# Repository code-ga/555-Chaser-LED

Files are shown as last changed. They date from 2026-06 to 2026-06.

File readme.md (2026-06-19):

# 555 Chaser LED

This is the one led board with 5 effects. These effects are:

- Blinky effect (each led will light-up then off for next led)
- Bit Counting (That is the calculator with led)
- Bar led ( These Stack up each clock )
- Breath effect ( fade up and fade down )
- On Mode ( their light up all led their have )

This is the result board

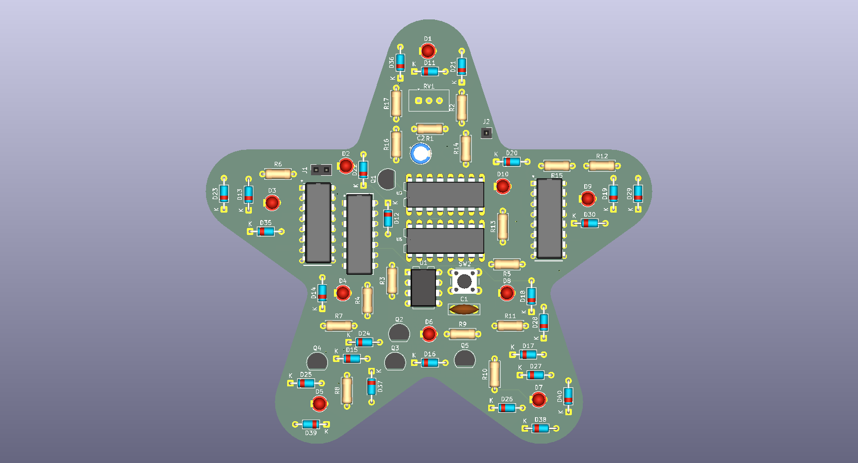
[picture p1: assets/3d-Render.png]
3D-Rendering


Also for someone want to know how that work

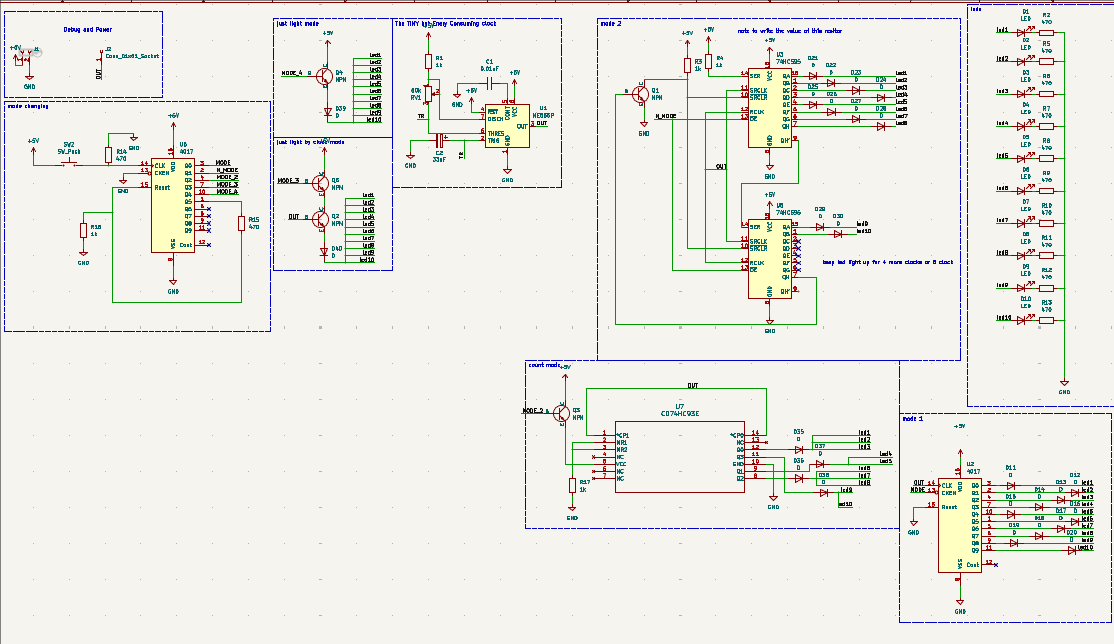
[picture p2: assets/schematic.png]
schematic


Also with the BOM (bill of material) of project is

| Reference | Qty | Value | Footprint | Datasheet | LCSC Part # | DIGIKEY_LINK | Price |
|---|-----|---|---|---|---|---|---|
| C1 | 1 | 0.01uF | Capacitor_THT:C_Disc_D7.5mm_W2.5mm_P5.00mm | | C52205045 | | 0.56  |
| C2 | 1 | 33uF | Capacitor_THT:CP_Radial_D5.0mm_P2.00mm | | C20539524 | | 0.74  |
| D1,D2,D3,D4,D5,D6,D7,D8,D9,D10 | 10  | LED | LED_THT:LED_D3.0mm | | C99772 | | 0.73  |
| D11,D12,D13,D14,D15,D16,D17,D18,D19,D20,D21,D22,D23,D24,D25,D26,D27,D28,D29,D30,D35,D36,D37,D38,D39,D40 | 26  | D | Diode_THT:D_DO-35_SOD27_P7.62mm_Horizontal | | C402212 | | 0.47  |
| J1 | 1 | | Connector_PinSocket_2.54mm:PinSocket_1x02_P2.54mm_Vertical | | C7499322 | | 0.46  |
| J2 | 1 | Conn_01x01_Socket | Connector_PinSocket_2.54mm:PinSocket_1x01_P2.54mm_Vertical | | C6302252 | | 1.15  |
| Q1,Q2,Q3,Q4,Q5 | 5 | NPN | Package_TO_SOT_THT:TO-92_Inline | https://ngspice.sourceforge.io/docs/ngspice-html-manual/manual.xhtml#cha_BJTs | C22751480 | | 0.75  |
| R1,R3,R4,R16,R17 | 5 | 1k | Resistor_THT:R_Axial_DIN0207_L6.3mm_D2.5mm_P7.62mm_Horizontal | | C3359542 | | 1.14  |
| R2,R5,R6,R7,R8,R9,R10,R11,R12,R13,R14,R15 | 12  | 470 | Resistor_THT:R_Axial_DIN0207_L6.3mm_D2.5mm_P7.62mm_Horizontal | | C1754684 | | 2.74  |
| RV1 | 1 | 50k | Potentiometer_THT:Potentiometer_Vishay_T93YA_Vertical | | C7061697 | | 3.2 |
| SW2 | 1 | SW_Push | Button_Switch_THT:SW_PUSH_6mm_H9.5mm | | C2689645 | https://www.digikey.com/en/products/detail/c-k/PVA1-OA-H1-1-2N-V2/417717 | 3.04  |
| U1 | 1 | NE555P | Package_DIP:DIP-8_W7.62mm | http://www.ti.com/lit/ds/symlink/ne555.pdf | C46749 | | 1.36  |
| U2,U6 | 2 | 4017 | CD4017BE:N16 | http://www.intersil.com/content/dam/Intersil/documents/cd40/cd4017bms-22bms.pdf | C32710674 | | 0.70  |
| U3,U5 | 2 | 74HC595 | 74HC595N:DIP16-2.54-20.32X5.84MM | http://www.ti.com/lit/ds/symlink/sn74hc595.pdf | C78711 | | 2.56  |
| U7 | 1 | CD74HC93E | 74HC93:N14 | https://www.ti.com/lit/gpn/cd74hc93 | C20345323 | | 2.29  |

[lcsc bom price](./assets/export_project_20260619_130623.xls)

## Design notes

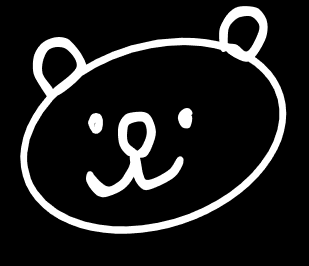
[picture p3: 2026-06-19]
assets/Merry Chrismas 1.png

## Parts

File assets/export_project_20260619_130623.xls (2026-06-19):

555-Chaser-LED.csv |  |  |  |  |  |  |  |  |  | LCSC BOM Quotation
 |  |  |  |  |  |  |  |  |  | BOM Date Created：19/06/26 01:09:42 |  |  |  | BOM Export Date: 19/06/26 13:06:23 |  |  |  | The matching result is a real-time query result, availability and prices may fluctuate. Backorder items are estimated prices for your reference, please submit "Create Quote" to get the real price. All information is provided "as is" and is subject to change without notice. Any use made of the information provided is without recourse to LCSC and at the user's risk.
 |  |  |  |  |  |  |  |  |  | EST TOTAL :$19.20 |  |  |  | Website：https://www.lcsc.com/bom | https://www.lcsc.com/bom | https://www.lcsc.com/bom | https://www.lcsc.com/bom
Uploaded data |  |  |  |  |  |  |  |  |  | LCSC Matching Results
LCSC# | Mfr. | Mrf# | Description | Package | Value | Customer Part Number | Quantity | Target Price(USD) | Target Lead Time(Business Days) | Mrf# | Mfr. | Order Qty. | Unit Price(USD) | Ext.Price(USD) | LCSC# | Package | Min | Mult | SPQ | Availability | Stock Status | Customer Notes | Description | Matched status | Product Link
C20539524 |  |  | 33uF | Capacitor_THT:CP_Radial_D5.0mm_P2.00mm |  | - | 1 |  |  | NPXB0801H330MJTM | Ymin | 5 | 0.1473 | 0.74 | C20539524 | Through Hole,D5xL8mm | 5 | 5 | 1000 | 705 | In Stock |  | 33uF ±20% 50V Through Hole,D5xL8mm 2000hrs@105℃ | Exact Matches | https://www.lcsc.com/product-detail/C20539524.html
C99772 |  |  | LED | LED_THT:LED_D3.0mm |  | - | 10 |  |  | 204-10SURD/S530-A3 | EVERLIGHT | 20 | 0.0365 | 0.73 | C99772 | Through Hole,D=3mm | 20 | 20 | 1000 | 96420 | In Stock |  | Red 632nm LED Indication - Discrete 2V Through Hole,D=3mm | Exact Matches | https://www.lcsc.com/product-detail/C99772.html
C402212 |  |  | D | Diode_THT:D_DO-35_SOD27_P7.62mm_Horizontal |  | - | 26 |  |  | 1N4148 | LGE | 50 | 0.0094 | 0.47 | C402212 | DO-35 | 50 | 50 | 5000 | 244100 | In Stock |  | Diode 75V 150mA Through Hole DO-35 | Exact Matches | https://www.lcsc.com/product-detail/C402212.html
C7499322 |  |  |  | Connector_PinSocket_2.54mm:PinSocket_1x02_P2.54mm_Vertical |  | - | 1 |  |  | ZX-PM2.54-1-2PY | Megastar | 5 | 0.0919 | 0.46 | C7499322 | Through Hole,P=2.54mm | 5 | 5 | 1000 | 31150 | In Stock |  | Female Header 2 Position 2.54mm Pitch Single Row Through Hole -40℃~+105℃ | Exact Matches | https://www.lcsc.com/product-detail/C7499322.html
C6302252 |  |  | Conn_01x01_Socket | Connector_PinSocket_2.54mm:PinSocket_1x01_P2.54mm_Vertical |  | - | 1 |  |  | SSW-101-03-G-S | Samtec | 1 | 1.1458 | 1.15 | C6302252 | Through Hole | 1 | 1 | 1000 | 34 | In Stock |  | Female Header 1 Position Single Row Through Hole -55℃~+125℃ | Exact Matches | https://www.lcsc.com/product-detail/C6302252.html
C22751480 |  |  | NPN | Package_TO_SOT_THT:TO-92_Inline |  | - | 5 |  |  | 2N4401052 | ALJ | 50 | 0.0149 | 0.75 | C22751480 | TO-92 | 50 | 50 | 1000 | 21000 | In Stock |  | Bipolar (BJT) Transistor NPN 40V 600mA 250MHz 1.5W Through Hole TO-92 | Exact Matches | https://www.lcsc.com/product-detail/C22751480.html
C3359542 |  |  | 1k | Resistor_THT:R_Axial_DIN0207_L6.3mm_D2.5mm_P7.62mm_Horizontal |  | - | 5 |  |  | MBB0207VD1001BC100 | VISHAY | 5 | 0.2284 | 1.14 | C3359542 | Through Hole,D2.5xL6.3mm | 1 | 1 | 1000 | 0 | Backordered |  | 1kΩ 400mW Metal Film Resistor ±25ppm/℃ ±0.1% Through Hole,D2.5xL6.3mm Through Hole Resistors RoHS | Exact Matches | https://www.lcsc.com/product-detail/C3359542.html
C1754684 |  |  | 470 | Resistor_THT:R_Axial_DIN0207_L6.3mm_D2.5mm_P7.62mm_Horizontal |  | - | 12 |  |  | PNP100JR-52-0R47 | YAGEO | 12 | 0.0507 | 0.61 | C1754684 | Through Hole,D2.5xL6.3mm | 1 | 1 | 5000 | 0 | Backordered |  | 470mΩ ±5% 1W Through Hole,D2.5xL6.3mm Wirewound Resistor | Exact Matches | https://www.lcsc.com/product-detail/C1754684.html
C7061697 |  |  | 50k | Potentiometer_THT:Potentiometer_Vishay_T93YA_Vertical |  | - | 1 |  |  | T93YA503KT20 | VISHAY | 1 | 3.2014 | 3.20 | C7061697 | Through Hole | 1 | 1 | 50 | 80 | In Stock |  | 50kΩ ±10% 500mW Through Hole Potentiometers, Variable Resistors | Exact Matches | https://www.lcsc.com/product-detail/C7061697.html
C2689645 |  |  | SW_Push | Button_Switch_THT:SW_PUSH_6mm_H9.5mm |  | - | 1 |  |  | PVA1OAH41.2NV2 | C&K | 1 | 3.0387 | 3.04 | C2689645 | Through Hole | 1 | 1 | 1500 | 1494 | In Stock |  | Without Non-Latching Double pole single throw Through Hole Square Plunger 1.2N Through Hole Pushbutton Switches RoHS | Exact Matches | https://www.lcsc.com/product-detail/C2689645.html
C46749 |  |  | NE555P | Package_DIP:DIP-8_W7.62mm |  | - | 1 |  |  | NE555P | TI | 5 | 0.2720 | 1.36 | C46749 | DIP-8 | 5 | 5 | 50 | 10420 | In Stock |  | DIP-8 Programmable Timers and Oscillators RoHS | Exact Matches | https://www.lcsc.com/product-detail/C46749.html
C32710674 |  |  | 4017 | CD4017BE:N16 |  | - | 2 |  |  | CD4017BE(LX) | lingxingic | 5 | 0.1399 | 0.70 | C32710674 | DIP-16 | 5 | 5 | 25 | 1640 | In Stock |  | Rising Edge 1 11MHz DIP-16 Counters, Dividers RoHS | Exact Matches | https://www.lcsc.com/product-detail/C32710674.html
C78711 |  |  | 74HC595 | 74HC595N:DIP16-2.54-20.32X5.84MM |  | - | 2 |  |  | SN74HC595N | TI | 2 | 1.2801 | 2.56 | C78711 | DIP-16 | 1 | 1 | 25 | 627 | In Stock |  | 2V~6V 1 6mA 26ns@6V,50pF Serial-to-Serial or Parallel DIP-16 Shift Registers RoHS | Exact Matches | https://www.lcsc.com/product-detail/C78711.html
C20345323 |  |  | CD74HC93E | 74HC93:N14 |  | - | 1 |  |  | CD74HC93EE4 | TI | 1 | 2.2862 | 2.29 | C20345323 | PDIP-14 | 1 | 1 | 25 | 0 | Backordered |  | PDIP-14 Counters, Dividers RoHS | Exact Matches | https://www.lcsc.com/product-detail/C20345323.html

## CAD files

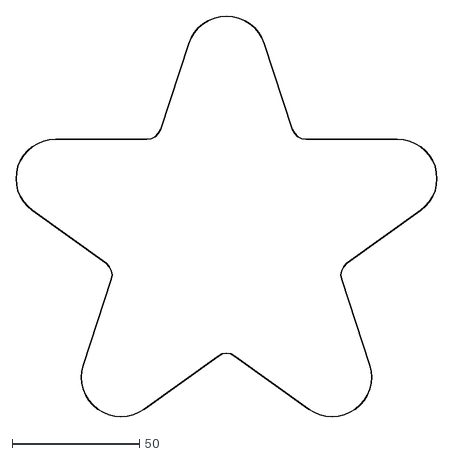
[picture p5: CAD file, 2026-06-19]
assets/vecteezy_colorful-cute-doodle-star-vector-illustration_13592912.dxf
165.6 x 157.4

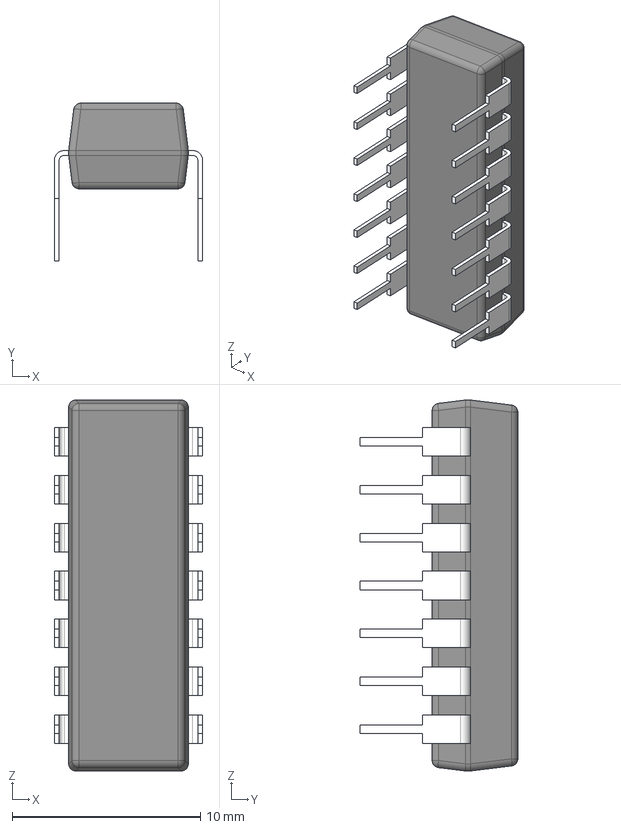
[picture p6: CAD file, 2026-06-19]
CD74HC93E/N0014A.stp
7.87 x 8.37 x 19.7 mm
BODY_N0014A_AF0
LEAD_N0014A_AF1
LEAD_N0014A x 10
LEAD_N0014A_AF3
LEAD_N0014A_AF0
LEAD_N0014A_AF2

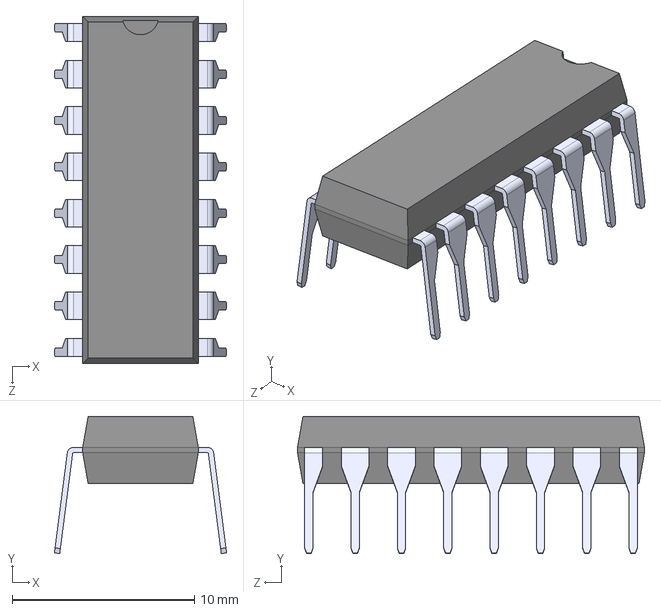
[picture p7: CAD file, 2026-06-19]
LOGIC-74HC595N_DIP16_/74HC595N.STEP
9.44 x 7.53 x 19.0 mm

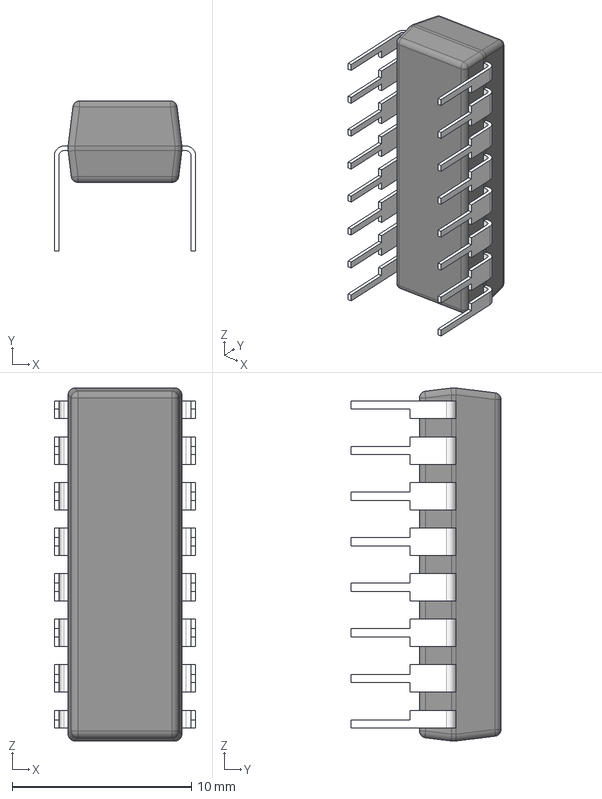
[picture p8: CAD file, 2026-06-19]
ul_CD4017BE/N0016A.stp
7.87 x 8.37 x 19.7 mm
BODY_N0016A_AF0
LEAD_N0016A_AF1
LEAD_N0016A x 10
LEAD_N0016A_AF3
LEAD_N0016A_AF5
LEAD_N0016A_AF0
LEAD_N0016A_AF2
LEAD_N0016A_AF4

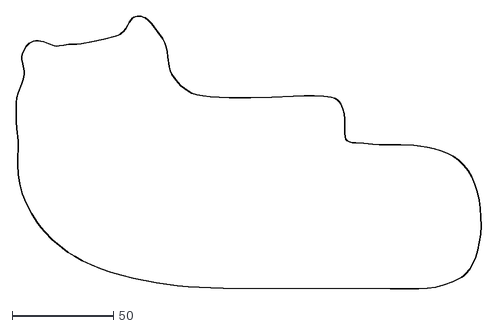
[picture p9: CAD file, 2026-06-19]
assets/Vector 3.dxf
230.0 x 134.8

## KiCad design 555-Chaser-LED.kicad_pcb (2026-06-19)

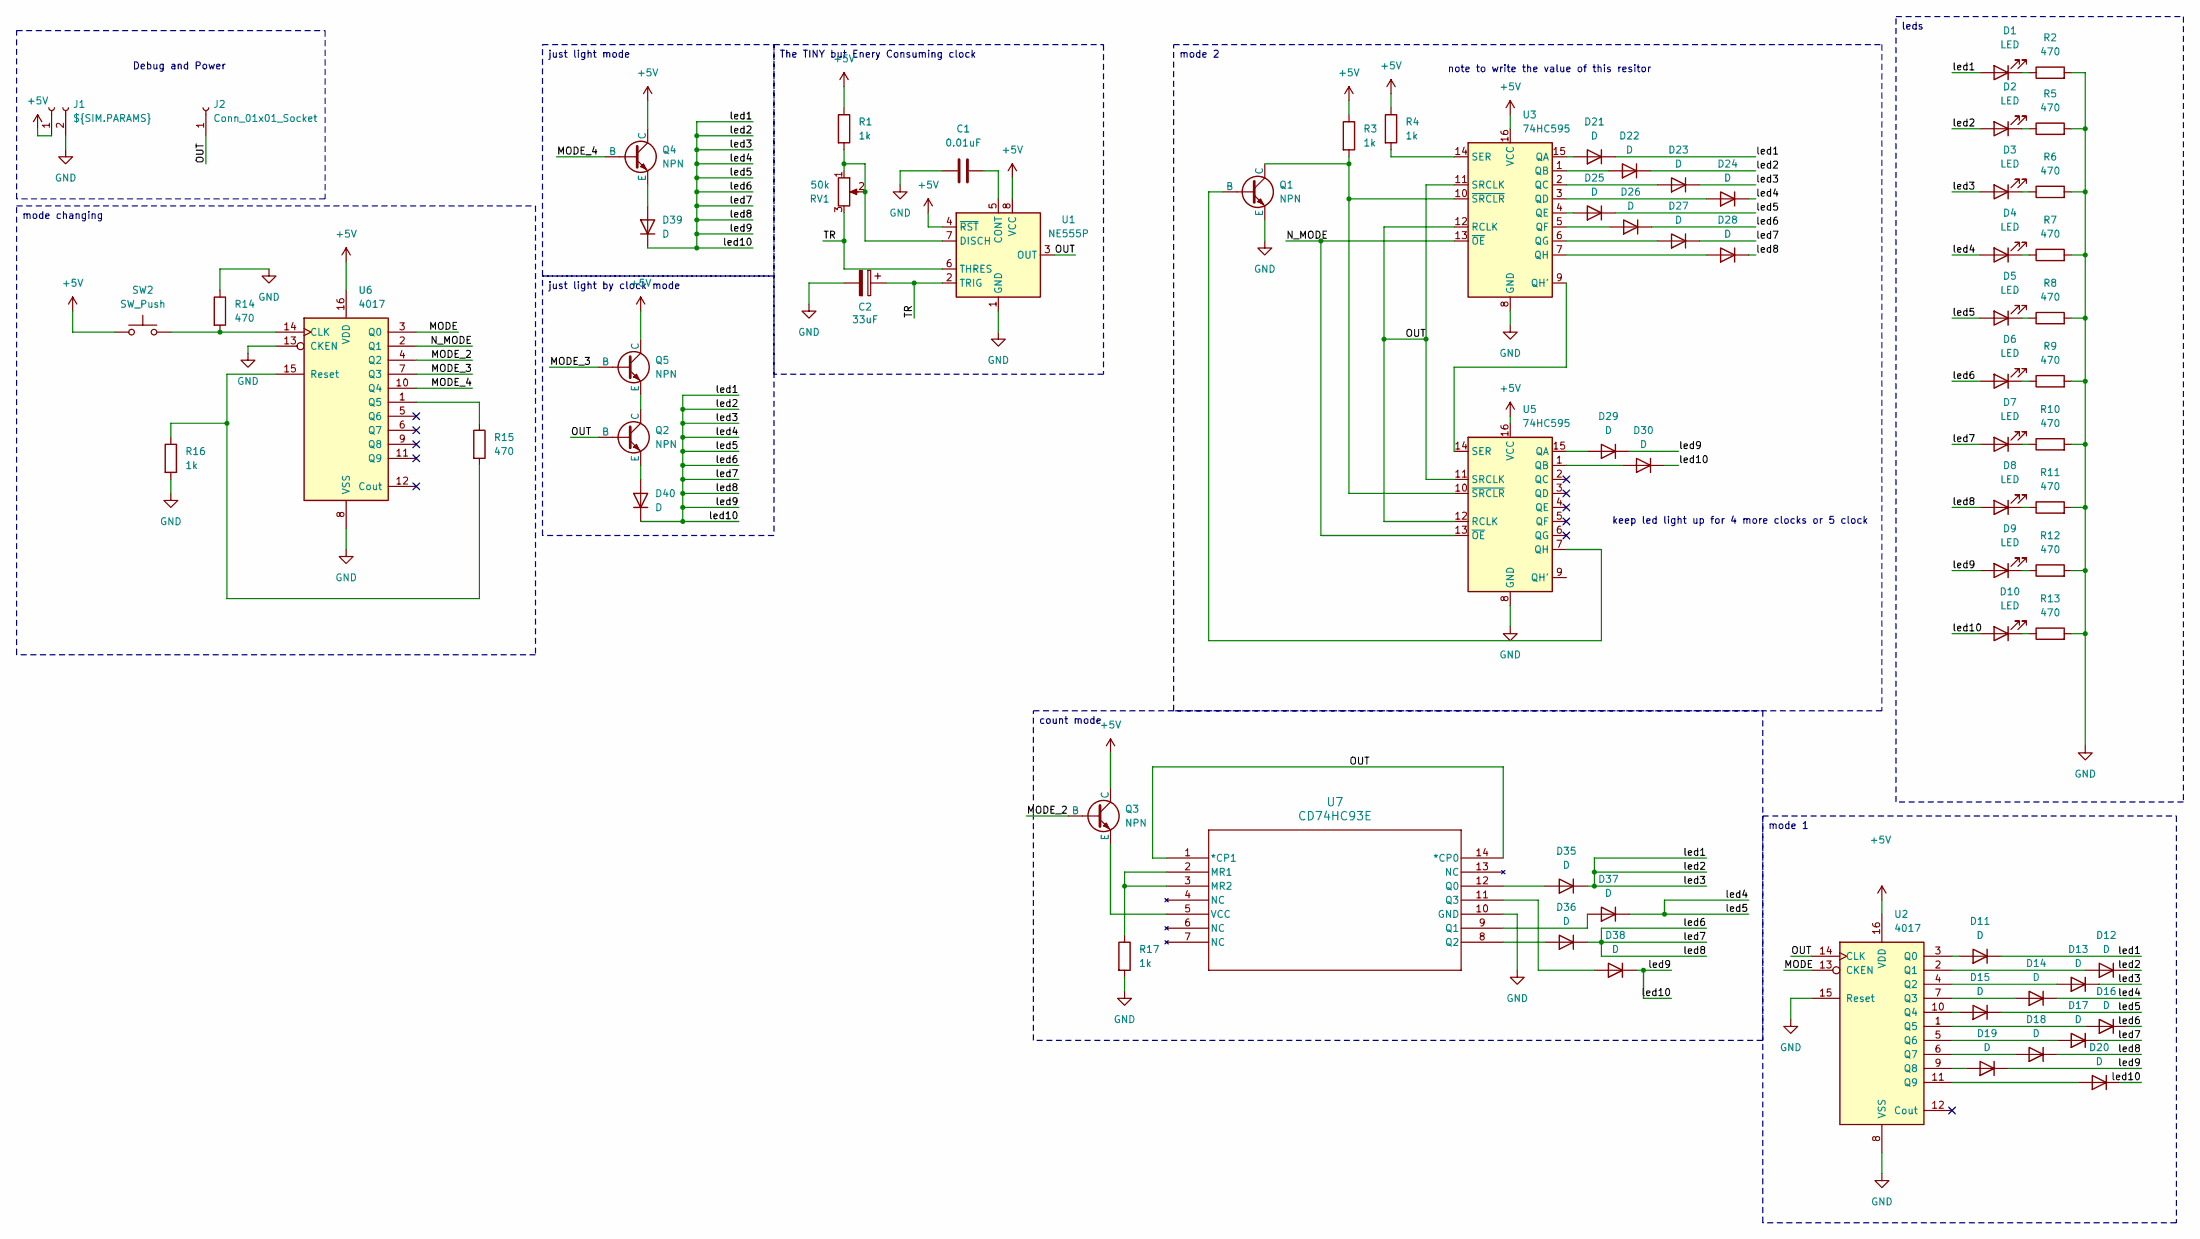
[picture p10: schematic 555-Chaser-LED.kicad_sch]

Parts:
C1: 0.01uF; C_Disc_D7.5mm_W2.5mm_P5.00mm
C2: 33uF; CP_Radial_D5.0mm_P2.00mm
D1, D2, D3, D4, D5, D6, D7, D8, D9, D10: LED; LED_D3.0mm
D11, D12, D13, D14, D15, D16, D17, D18, D19, D20, D21, D22, D23, D24, D25, D26, D27, D28, D29, D30, D35, D36, D37, D38, D39, D40: D; D_DO-35_SOD27_P7.62mm_Horizontal
J1: ${SIM.PARAMS}; PinSocket_1x02_P2.54mm_Vertical
J2: Conn_01x01_Socket; PinSocket_1x01_P2.54mm_Vertical
Q1, Q2, Q3, Q4, Q5: NPN; TO-92_Inline
R1, R3, R4, R16, R17: 1k; R_Axial_DIN0207_L6.3mm_D2.5mm_P7.62mm_Horizontal
R2, R5, R6, R7, R8, R9, R10, R11, R12, R13, R14, R15: 470; R_Axial_DIN0207_L6.3mm_D2.5mm_P7.62mm_Horizontal
RV1: 50k; Potentiometer_Vishay_T93YA_Vertical
SW2: SW_Push; SW_PUSH_6mm_H9.5mm
U1: NE555P; DIP-8_W7.62mm
U2, U6: 4017; N16
U3, U5: 74HC595; DIP16-2.54-20.32X5.84MM
U7: CD74HC93E; N14

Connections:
+5V: J1.1, Q3.1 (C), Q4.1 (C), Q5.1 (C), R1.1, R3.1, R4.1, SW2.1, U1.4 (~RST), U1.8 (VCC), U2.16 (VDD), U3.16 (VCC), U5.16 (VCC), U6.16 (VDD)
/MODE: U2.13 (CKEN), U6.3 (Q0)
/MODE_2: Q3.2 (B), U6.4 (Q2)
/MODE_3: Q5.2 (B), U6.7 (Q3)
/MODE_4: Q4.2 (B), U6.10 (Q4)
/N_MODE: U3.13 (~OE), U5.13 (~OE), U6.2 (Q1)
/OUT: J2.1 (Pin_1_1), Q2.2 (B), U1.3 (OUT), U2.14 (CLK), U3.11 (SRCLK), U3.12 (RCLK), U5.11 (SRCLK), U5.12 (RCLK), U7.1 (*CP1), U7.14 (*CP0)
/TR: C2.1, RV1.3, U1.2 (TRIG), U1.6 (THRES)
/led1: D1.2 (A), D2.2 (A), D3.2 (A), D4.2 (A), D5.2 (A), D6.2 (A), D7.2 (A), D8.2 (A), D9.2 (A), D10.2 (A), D11.1 (K), D12.1 (K), D13.1 (K), D14.1 (K), D15.1 (K), D16.1 (K), D17.1 (K), D18.1 (K), D19.1 (K), D20.1 (K), D21.1 (K), D22.1 (K), D23.1 (K), D24.1 (K), D25.1 (K), D26.1 (K), D27.1 (K), D28.1 (K), D29.1 (K), D30.1 (K), D35.1 (K), D36.1 (K), D37.1 (K), D38.1 (K), D39.1 (K), D40.1 (K)
GND: C1.1, C2.2, J1.2, Q1.3 (E), R2.2, R5.2, R6.2, R7.2, R8.2, R9.2, R10.2, R11.2, R12.2, R13.2, R14.1, R16.2, R17.2, U1.1 (GND), U2.8 (VSS), U2.15 (Reset), U3.8 (GND), U5.8 (GND), U6.8 (VSS), U6.13 (CKEN), U7.10 (GND)
unnamed: D1.1 (K), R2.1
unnamed: D2.1 (K), R5.1
unnamed: D3.1 (K), R6.1
unnamed: D4.1 (K), R7.1
unnamed: D5.1 (K), R8.1
unnamed: D6.1 (K), R9.1
unnamed: D7.1 (K), R10.1
unnamed: D8.1 (K), R11.1
unnamed: D9.1 (K), R12.1
unnamed: D10.1 (K), R13.1
unnamed: D11.2 (A), U2.3 (Q0)
unnamed: D12.2 (A), U2.2 (Q1)
unnamed: D13.2 (A), U2.4 (Q2)
unnamed: D14.2 (A), U2.7 (Q3)
unnamed: D15.2 (A), U2.10 (Q4)
unnamed: D16.2 (A), U2.1 (Q5)
unnamed: D17.2 (A), U2.5 (Q6)
unnamed: D18.2 (A), U2.6 (Q7)
unnamed: D19.2 (A), U2.9 (Q8)
unnamed: D20.2 (A), U2.11 (Q9)
unnamed: D21.2 (A), U3.15 (QA)
unnamed: D22.2 (A), U3.1 (QB)
unnamed: D23.2 (A), U3.2 (QC)
unnamed: D24.2 (A), U3.3 (QD)
unnamed: D25.2 (A), U3.4 (QE)
unnamed: D26.2 (A), U3.5 (QF)
unnamed: D27.2 (A), U3.6 (QG)
unnamed: D28.2 (A), U3.7 (QH)
unnamed: D29.2 (A), U5.15 (QA)
unnamed: D30.2 (A), U5.1 (QB)
unnamed: D35.2 (A), U7.12 (Q0)
unnamed: D36.2 (A), U7.8 (Q2)
unnamed: D37.2 (A), U7.9 (Q1)
unnamed: D38.2 (A), U7.11 (Q3)
unnamed: D39.2 (A), Q4.3 (E)
unnamed: D40.2 (A), Q2.3 (E)
unnamed: Q1.2 (B), U5.7 (QH)
unnamed: Q1.1 (C), R3.2, U3.10 (~SRCLR), U5.10 (~SRCLR)
unnamed: Q2.1 (C), Q5.3 (E)
unnamed: Q3.3 (E), U7.5 (VCC)
unnamed: C1.2, U1.5 (CONT)
unnamed: R1.2, RV1.1, RV1.2, U1.7 (DISCH)
unnamed: U3.9 (QH'), U5.14 (SER)
unnamed: R4.2, U3.14 (SER)
unnamed: R14.2, SW2.2, U6.14 (CLK)
unnamed: R15.1, U6.1 (Q5)
unnamed: R15.2, R16.1, U6.15 (Reset)
unnamed: R17.1, U7.2 (MR1), U7.3 (MR2)

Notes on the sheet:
keep led light up for 4 more clocks or 5 clock
note to write the value of this resitor
Debug and Power
mode changing
just light mode
mode 1
The TINY but Enery Consuming clock
just light by clock mode
count mode
mode 2
leds

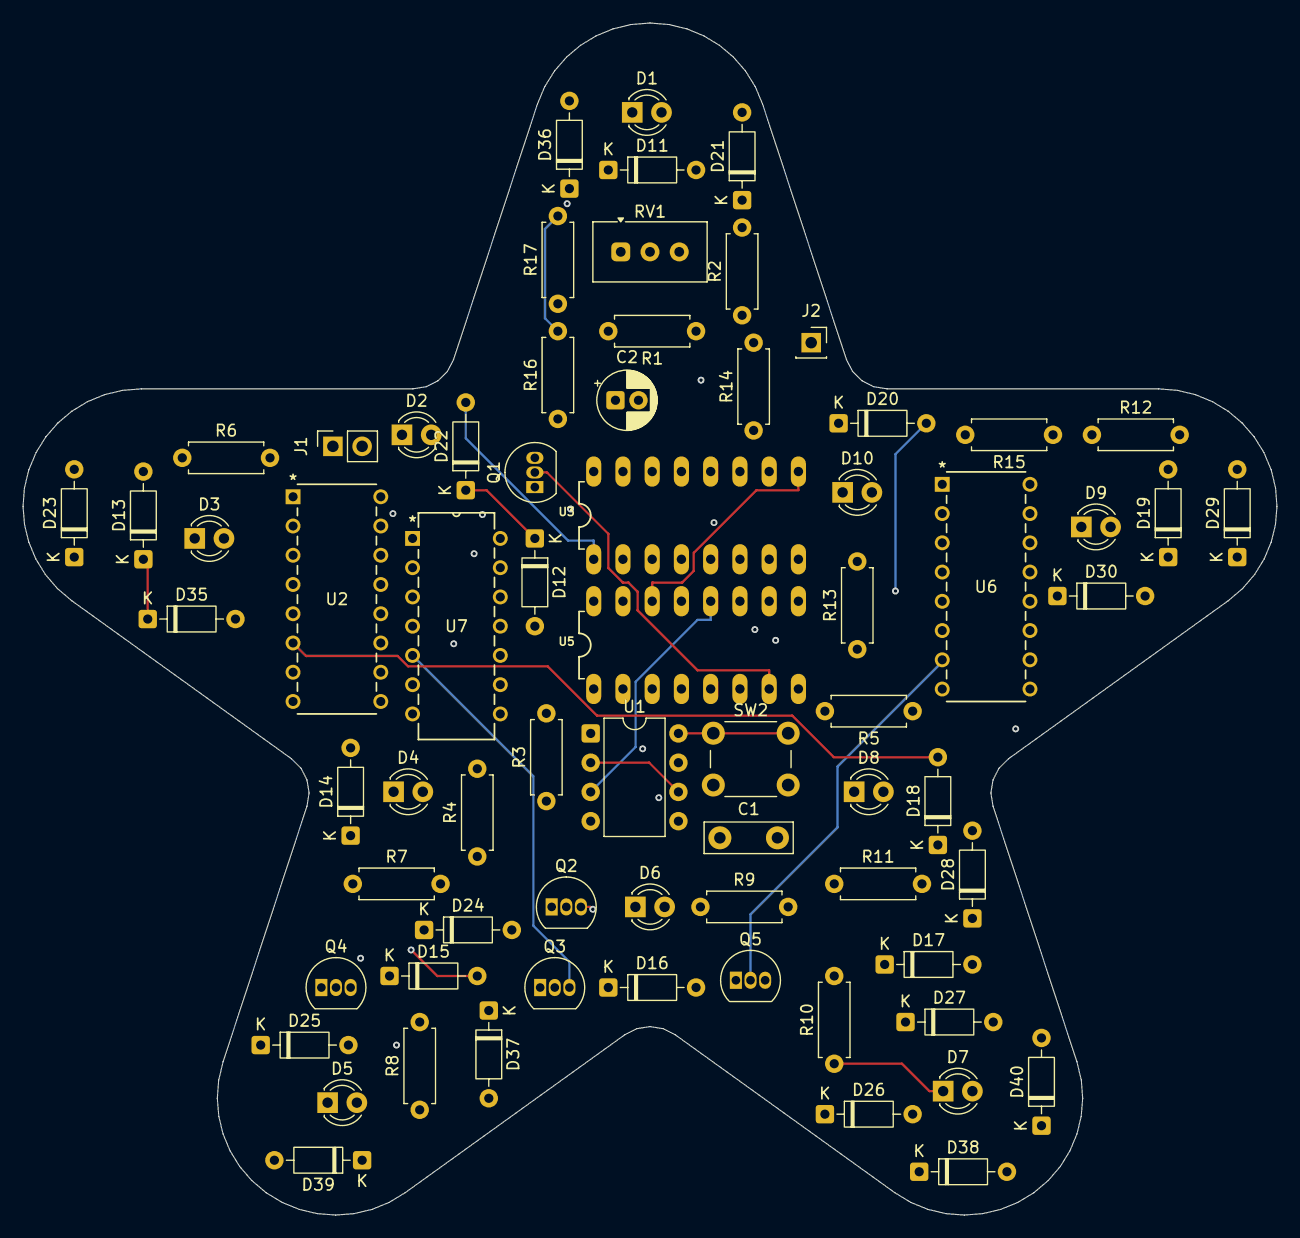
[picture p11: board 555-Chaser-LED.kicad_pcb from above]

Board: 4 copper layers, 108.9 x 103.5 mm, 70 parts (0 on the bottom side), 58 nets.

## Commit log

2026-06-19 init commit
    [555-Chaser-LED.kicad_pcb, 555-Chaser-LED.kicad_sch, 74HC595N.STEP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]
2026-06-19 adding bom.csv
    [BOM.csv]
